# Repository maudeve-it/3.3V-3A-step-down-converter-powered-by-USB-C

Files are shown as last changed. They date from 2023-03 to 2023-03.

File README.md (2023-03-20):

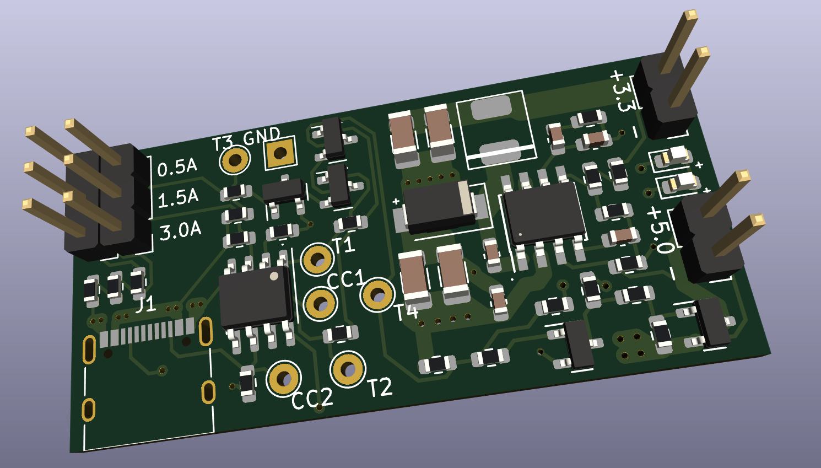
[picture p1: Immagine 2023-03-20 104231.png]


# A 3.3V/3A step-down converter powered via USB-C
<br>
Without needing to use a USB-C PD controller chip, handling communication over the USB cable, USB-C standard allows to get 5V up to 3A through a hardware availability detection.<br> Here I show a design developed on KiCad and assembled through JLCPCB. It is sinking power from a USB-PD connector and provides 5V and 3.3V up to 3A through a step-down converter.<br>
<br>
Project was developed on KiCad 7<br>
<br>
You can find details about this project on the YouTube video: https://youtu.be/P4Y0VTdbARY
<br>
<br>
<i>
  
_**PLEASE NOTE**_<br>
Seeing the video is strongly suggested.<br>
Project stored here is what developed and tested on YouTube.<br>
Once connected to a USB-C PD source it shows a "transient" for about 12 seconds. Avoiding it, a filtering caoacitor should be added.<br>
Again as shown in the video.<br>
</i>
<br>
<br>

---
---

<br>
<br>
<br>

# Uno stabilizzatore step-down 3.3V/3A alimentato via USB-C

<br>
Senza la necessità di usare un controller chip per USB-C PD, che gestisce la comunicazione sul cavo USB, lo standard USB permette di prelevare 5V fino a 3A controllando la disponibilità via hardware.<br>
Qui mostro un progetto realizzato su KiCad e realizzato attraverso JLCPCB, di alimentatore che preleva corrente una porta USB-PD e fornisce 5V e 3.3V fino a 3A attraverso uno step-down converter.<br>
<br>
Il progetto è stato realizzato su KiCad 7<br>
<br>
Puoi trovare i dettagli sul progetto nel video YouTube: https://youtu.be/P4Y0VTdbARY
<br>
<br>
<i>
  
_**NOTA BENE**_<br>
Vedere il video è fortemente suggerito.<br>
Il progetto archiviato qui è quello sviluppato e testato su YouTube.<br>
Connesso ad una alimentazione USB-C PD, mostra un "transitorio" di circa 12 secondi e per evitarlo si deve aggiungere un condensatore di filtro.<br>
Ancora come mostrato nel video.<br>
</i>

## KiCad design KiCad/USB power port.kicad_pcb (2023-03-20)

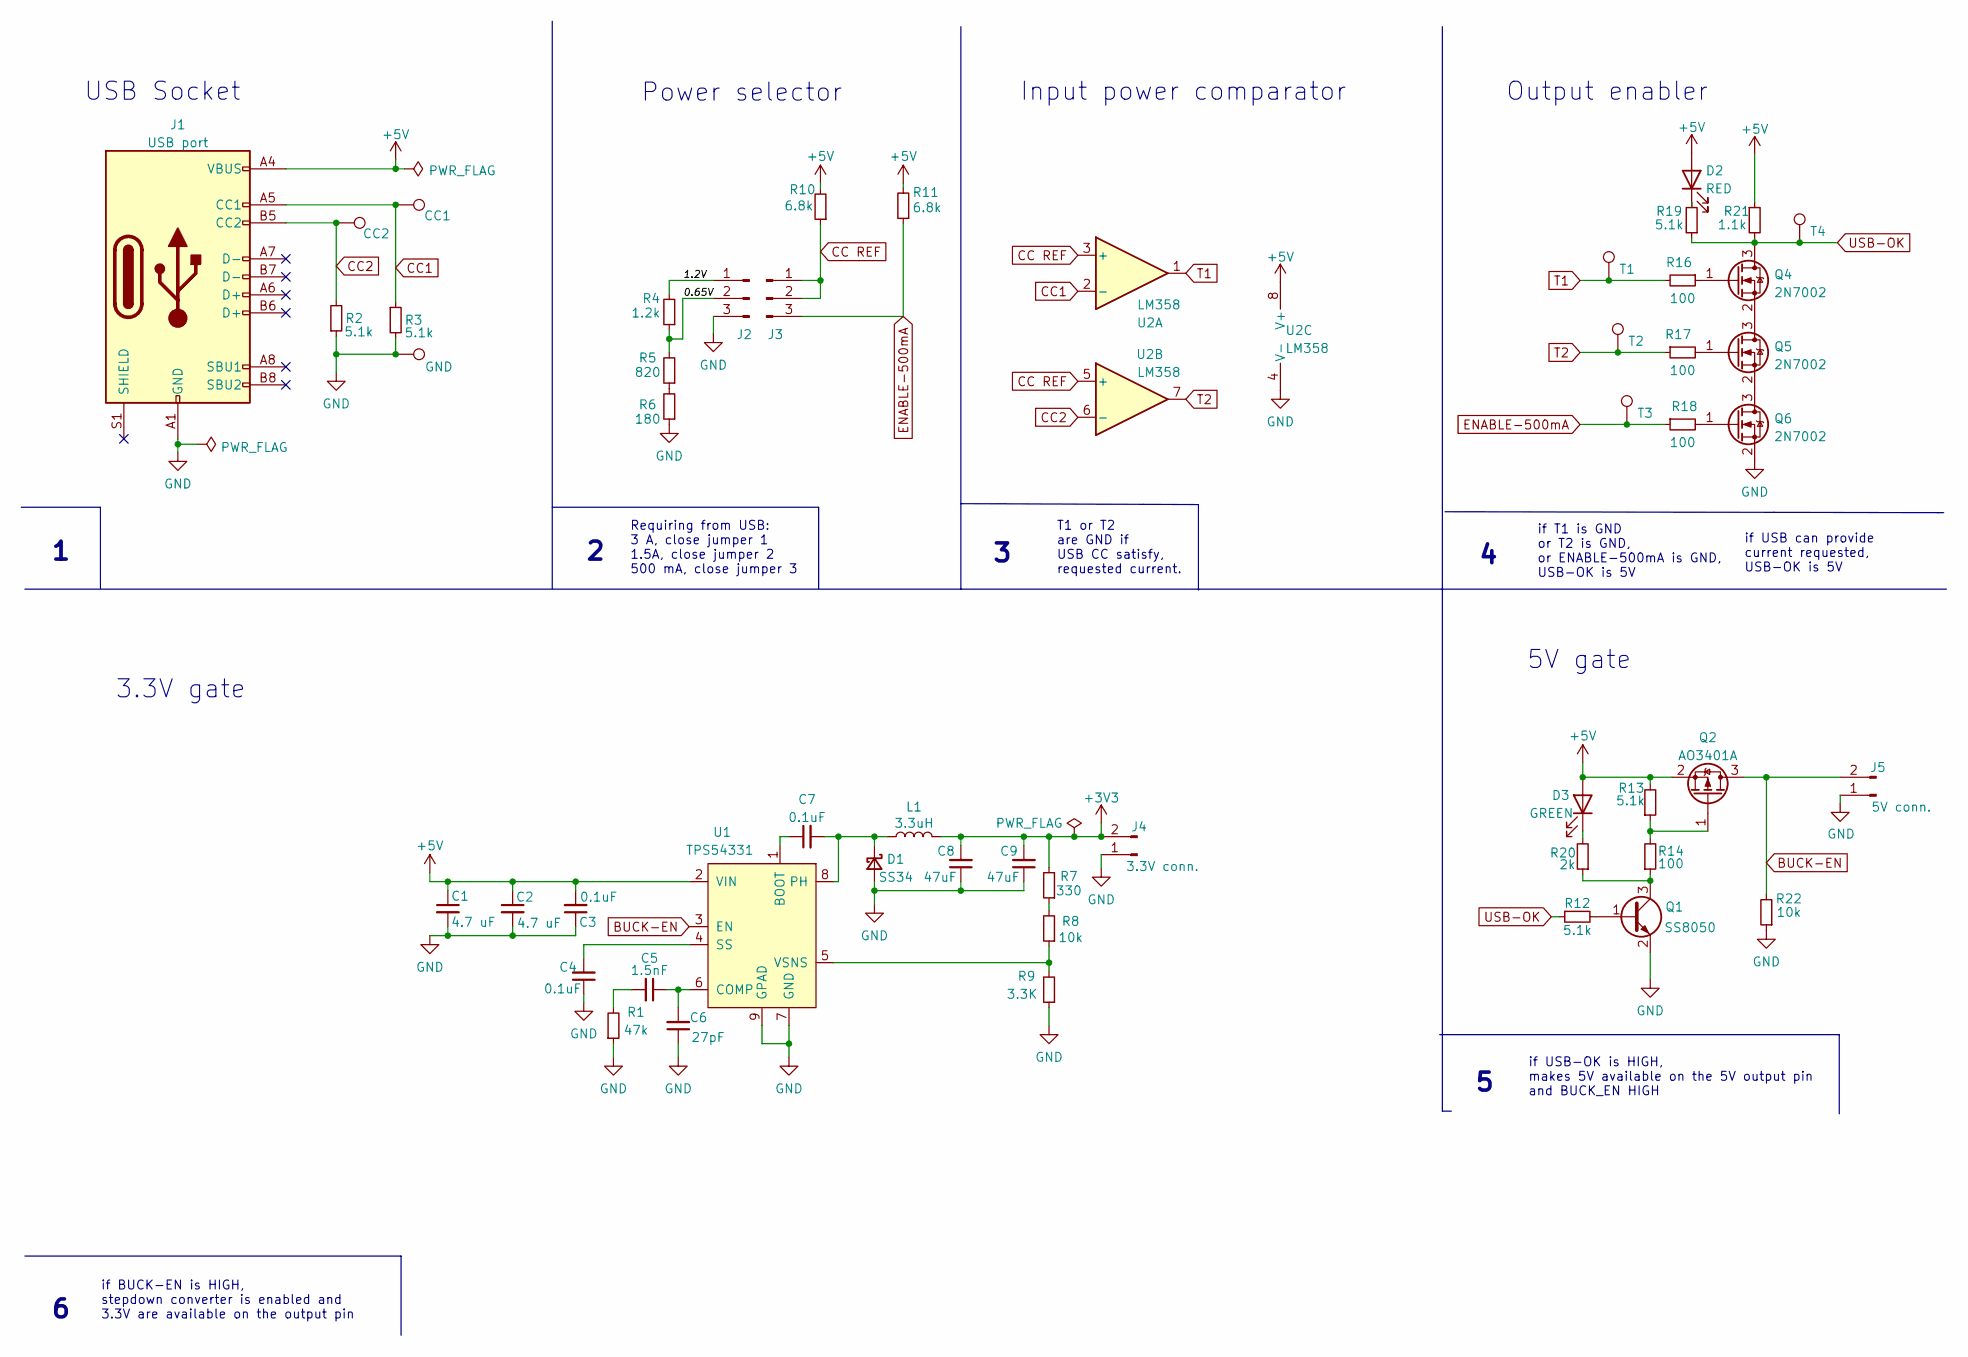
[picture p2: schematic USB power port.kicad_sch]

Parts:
C1, C2: 4.7 uF; C_1206_3216Metric; PartNo C29823
C3, C4, C7: 0.1uF; C_0603_1608Metric; PartNo C14663
C5: 1.5nF; C_0603_1608Metric; PartNo C1595
C6: 27pF; C_0603_1608Metric; PartNo C107045
C8, C9: 47uF; C_1206_3216Metric; PartNo C96123
D1: SS34; D_SMA; PartNo C8678
D2: RED; LED_0603_1608Metric; PartNo C2286
D3: GREEN; LED_0603_1608Metric; PartNo C72043
J1: USB port; USB_C_Receptacle_XKB_U262-16XN-4BVC11; PartNo C319148
J2, J3: Selector; PinHeader_1x03_P2.54mm_Vertical
J4: 3.3V conn.; PinHeader_1x02_P2.54mm_Vertical
J5: 5V conn.; PinHeader_1x02_P2.54mm_Vertical
L1: 3.3uH; MWSA0402; PartNo C285742
Q1: SS8050; SOT-23; PartNo C2150
Q2: AO3401A; SOT-23; PartNo C15127
Q4, Q5, Q6: 2N7002; SOT-23; PartNo C8545
R1: 47k; R_0603_1608Metric; PartNo C25819
R2, R3, R12, R13, R19: 5.1k; R_0603_1608Metric; PartNo C23186
R4: 1.2k; R_0603_1608Metric; PartNo C22765
R5: 820; R_0603_1608Metric; PartNo C23253
R6: 180; R_0603_1608Metric; PartNo C22828
R7: 330; R_0603_1608Metric; PartNo C23138
R8, R22: 10k; R_0603_1608Metric; PartNo C25804
R9: 3.3K; R_0603_1608Metric; PartNo C22978
R10, R11: 6.8k; R_0603_1608Metric; PartNo C23212
R14, R16, R17, R18: 100; R_0603_1608Metric; PartNo C22775
R20: 2k; R_0603_1608Metric; PartNo C22975
R21: 1.1k; R_0603_1608Metric; PartNo C22764
TP1: CC2; TestPoint_THTPad_D2.0mm_Drill1.0mm
TP2: CC1; TestPoint_THTPad_D2.0mm_Drill1.0mm
TP3: GND; TestPoint_THTPad_2.0x2.0mm_Drill1.0mm
TP4: T1; TestPoint_THTPad_D2.0mm_Drill1.0mm
TP5: T2; TestPoint_THTPad_D2.0mm_Drill1.0mm
TP6: T3; TestPoint_THTPad_D2.0mm_Drill1.0mm
TP7: T4; TestPoint_THTPad_D2.0mm_Drill1.0mm
U1: TPS54331; TI_SO-PowerPAD-8_ThermalVias; PartNo C9865
U2: LM358; SOIC-8_3.9x4.9mm_P1.27mm; PartNo C7950

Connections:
+3V3: C8.2, C9.2, J4.2, L1.2, R7.2
+5V: C1.1, C2.1, C3.2, D2.2 (A), D3.2 (A), J1.A4 (VBUS), J1.A9 (VBUS), J1.B4 (VBUS), J1.B9 (VBUS), Q2.2 (S), R10.2, R11.2, R13.2, R21.1, U1.2 (VIN), U2.8 (V+)
/0.65V: J2.2, R4.1, R5.2
/1.2V: J2.1, R4.2
BUCK-EN: J5.2, Q2.3 (D), R22.2, U1.3 (EN)
CC1: J1.A5 (CC1), R3.1, TP2.1, U2.2 (-)
CC2: J1.B5 (CC2), R2.2, TP1.1, U2.6 (-)
CC REF: J3.1, J3.2, R10.1, U2.3 (+), U2.5 (+)
ENABLE-500mA: J3.3, R11.1, R18.1, TP6.1
GND: C1.2, C2.2, C3.1, C4.1, C6.1, C8.1, C9.1, D1.2 (A), J1.A1 (GND), J1.A12 (GND), J1.B1 (GND), J1.B12 (GND), J2.3, J4.1, J5.1, Q1.2 (E), Q6.2 (S), R1.1, R2.1, R3.2, R6.1, R9.1, R22.1, TP3.1, U1.7 (GND), U1.9 (GPAD), U2.4 (V-)
unnamed: C5.2, R1.2
unnamed: C7.2, D1.1 (K), L1.1, U1.8 (PH)
unnamed: D2.1 (K), R19.2
unnamed: D3.1 (K), R20.2
unnamed: Q1.1 (B), R12.2
unnamed: Q1.3 (C), R14.1, R20.1
unnamed: Q2.1 (G), R13.1, R14.2
unnamed: Q4.1 (G), R16.1
unnamed: Q4.2 (S), Q5.3 (D)
unnamed: Q5.1 (G), R17.2
unnamed: Q5.2 (S), Q6.3 (D)
unnamed: Q6.1 (G), R18.2
unnamed: R5.1, R6.2
unnamed: R7.1, R8.2
unnamed: C7.1, U1.1 (BOOT)
unnamed: C5.1, C6.2, U1.6 (COMP)
unnamed: C4.2, U1.4 (SS)
unnamed: R8.1, R9.2, U1.5 (VSNS)
T1: R16.2, TP4.1, U2.1
T2: R17.1, TP5.1, U2.7
USB-OK: Q4.3 (D), R12.1, R19.1, R21.2, TP7.1

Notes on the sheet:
Input power comparator
if BUCK-EN is HIGH, stepdown converter is enabled and 3.3V are available on the output pin
if USB-OK is HIGH, makes 5V available on the 5V output pin and BUCK_EN HIGH
USB Socket
Output enabler
if USB can provide current requested, USB-OK is 5V
if T1 is GND or T2 is GND, or ENABLE-500mA is GND, USB-OK is 5V
T1 or T2 are GND if USB CC satisfy, requested current.
Power selector
Requiring from USB: 3 A, close jumper 1 1.5A, close jumper 2 500 mA, close jumper 3
5V gate
3.3V gate

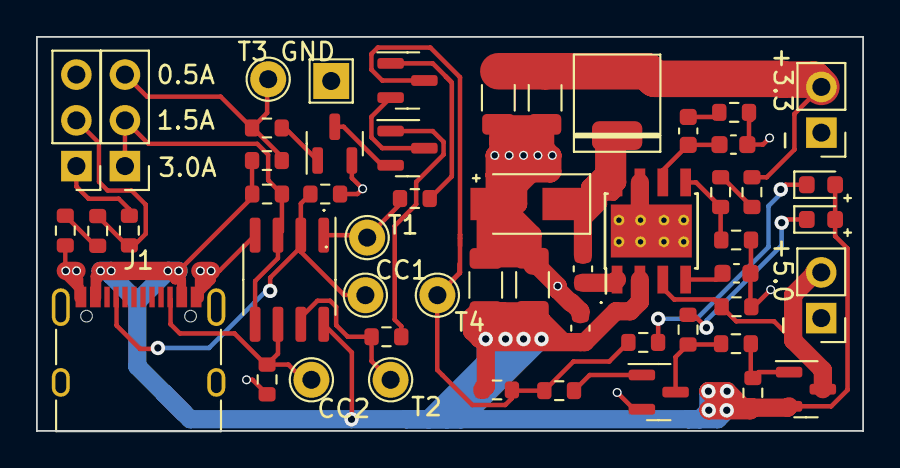
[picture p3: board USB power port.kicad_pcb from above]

Board: 2 copper layers, 45.9 x 21.9 mm, 53 parts (0 on the bottom side), 31 nets.
